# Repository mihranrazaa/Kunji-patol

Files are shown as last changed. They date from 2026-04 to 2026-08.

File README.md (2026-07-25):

# KUNJI-PATOL-75% KEYBOARD!

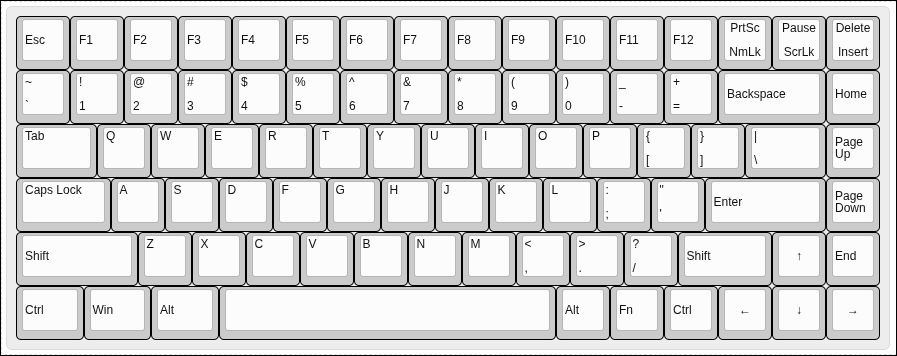
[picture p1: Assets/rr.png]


## Overview
a 75%% keyboard design, it is based on RP2040 plus with a type C port which came in-built with the MCU, there total of 87 MX switches with 5 Stabilizers. A complete keyboard :).


### Working Video

<video src="https://cdn.jsdelivr.net/gh/mihranrazaa/Kunji-patol@main/Assets/working.mp4" controls width="100%"></video>

I can't add the video on readme as it the file is big.. i have added it in the assets folder.. 
But here is the GDrive link [Link](https://drive.google.com/file/d/1fuCprYtJpbeOFGNmlc98sxJG4bjCoqw0/view?usp=sharing)

---

## Bit in depth info
The keyboard is designed to be sleek and plane it has RP2040 plus as the MCU and Cherry MX Brown Switches for the keys which are used for versatile purposes (that's what i saw at least). The main firmware is KMK based and the Firmware has already been released, you can find that in the Firmware and Production folder, I hate using different cables so having type c inbuilt in the RP2040 plus is a win-win. I tried to built a unique design but routing diodes was hell, at the end the pcb looks very good in black color, hope you like my project :).

---

## Files to build 

### PCB 

The files for the PCB and Schematics are available in the Kicad folder and gerber files are added in the Production folder..

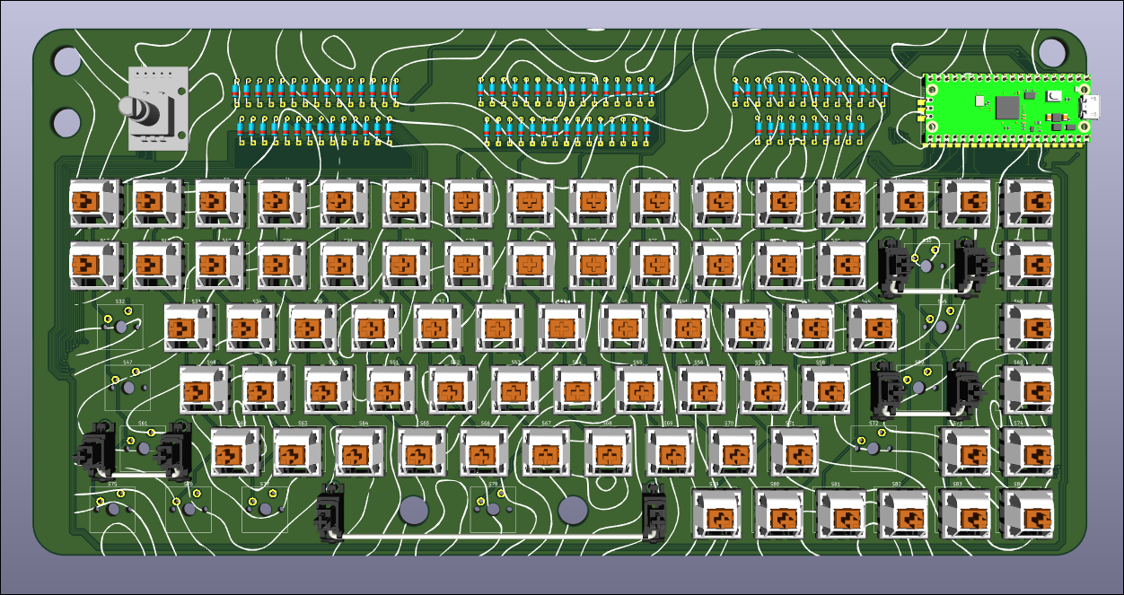
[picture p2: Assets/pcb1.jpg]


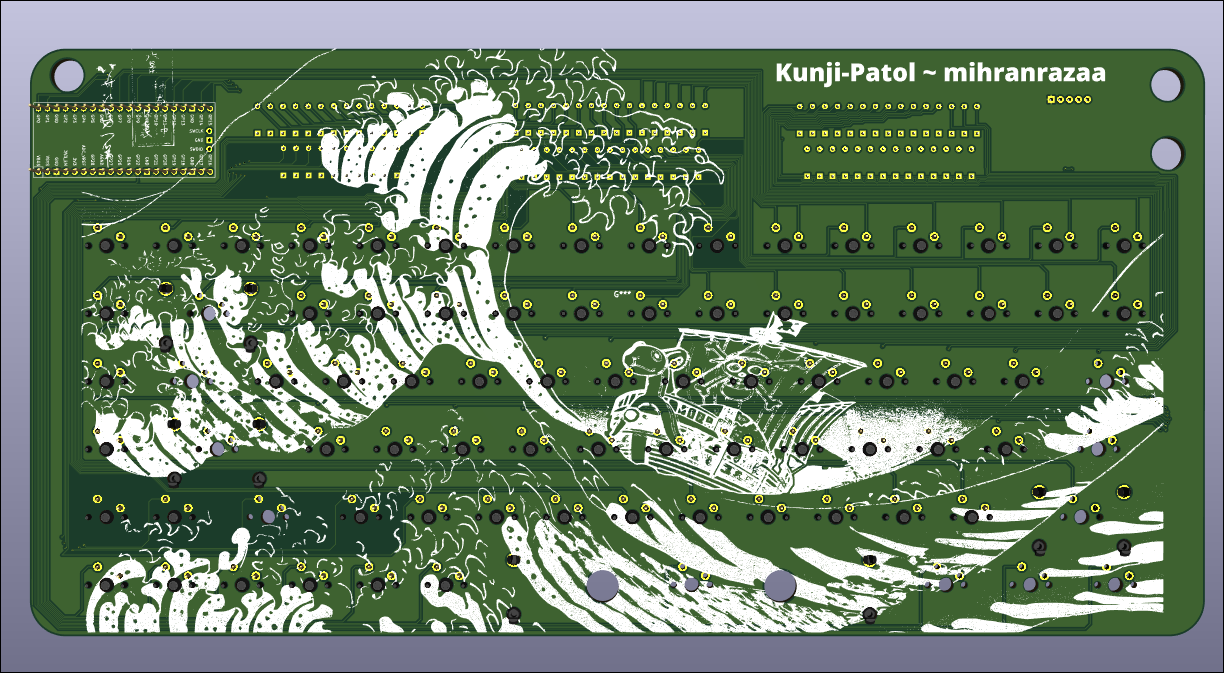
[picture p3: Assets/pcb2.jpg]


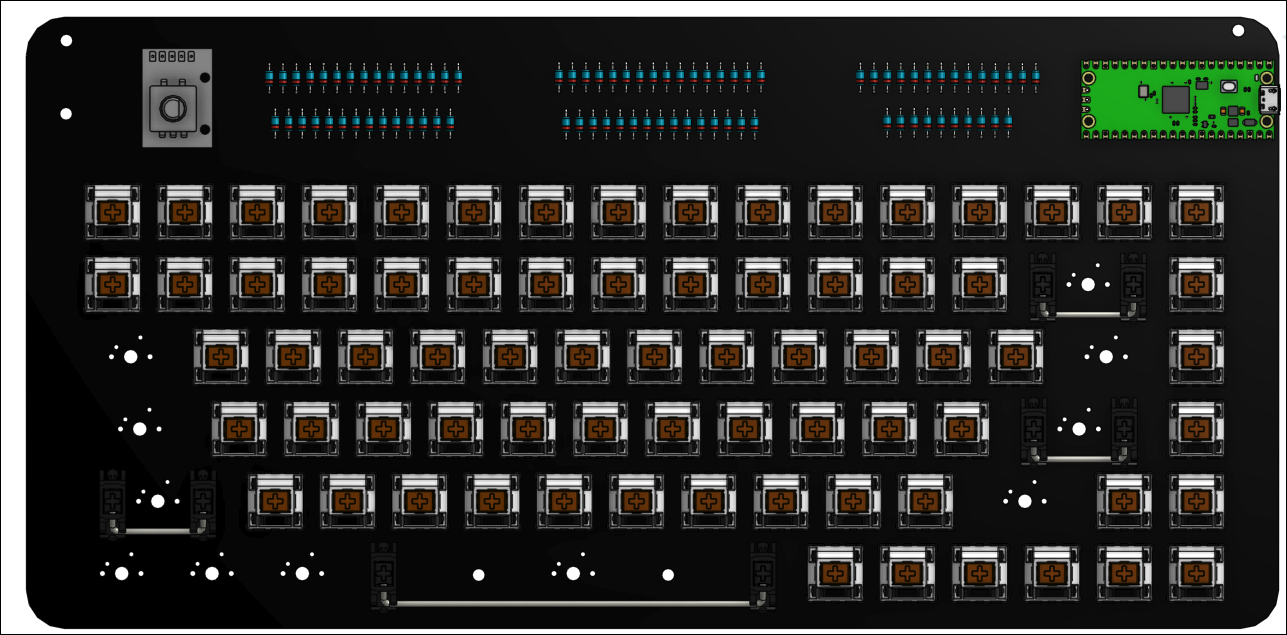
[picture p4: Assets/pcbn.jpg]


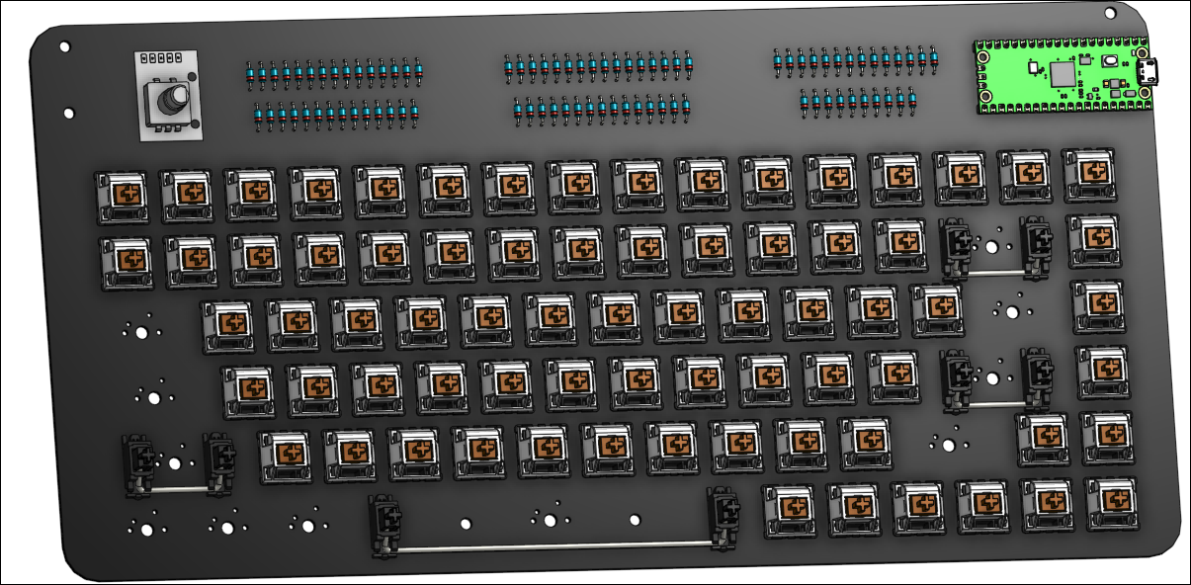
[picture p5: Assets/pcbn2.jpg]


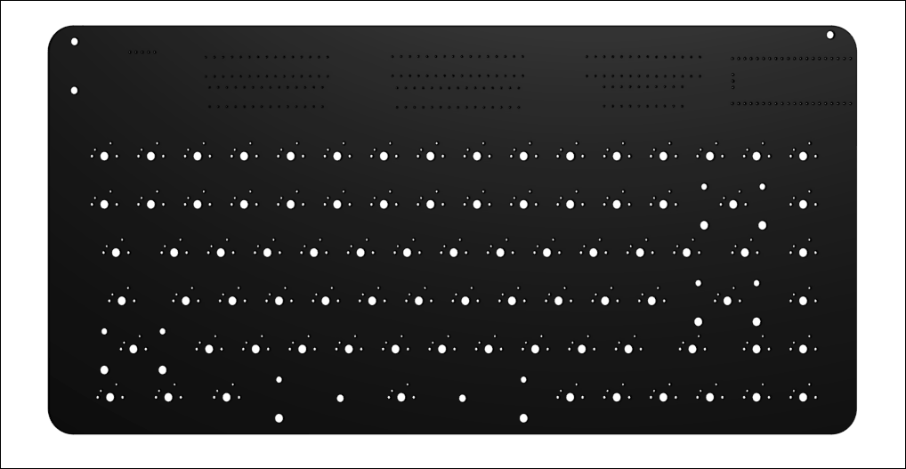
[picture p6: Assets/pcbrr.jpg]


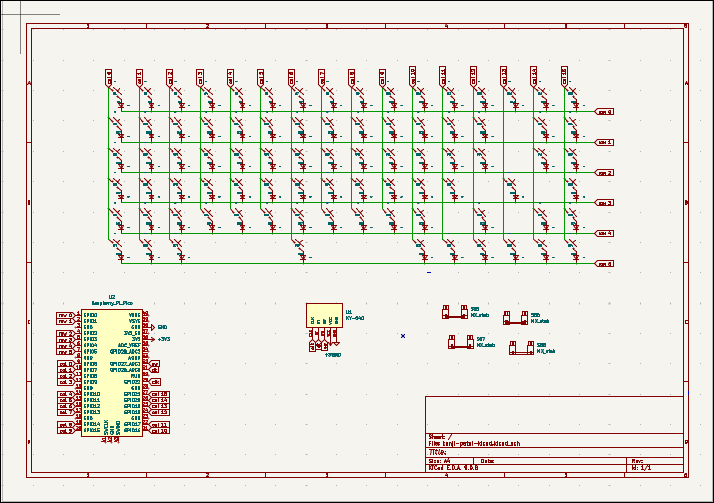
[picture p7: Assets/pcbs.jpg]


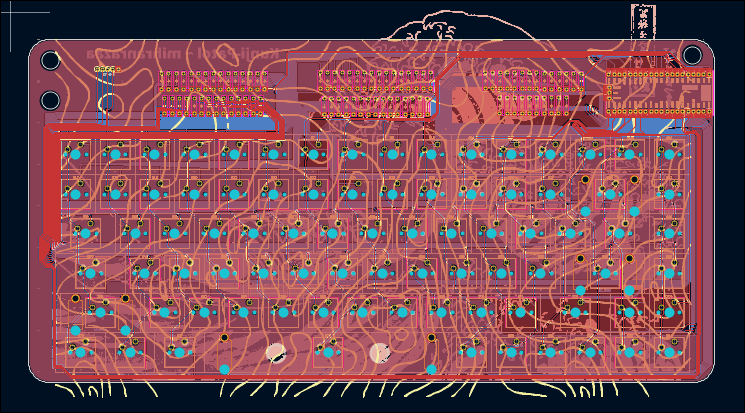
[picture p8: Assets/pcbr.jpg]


## Images

The files for case and plate cover are available in CAD folder and in production folder, you can also but acrylic sheet for the transparent plate.

Onshape Link - [Here](https://cad.onshape.com/documents/a8c5ad1b41baae53f41fa56c/w/8619affa68464bad5057e5ce/e/6ca96762f7cb8c02978ccc82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)

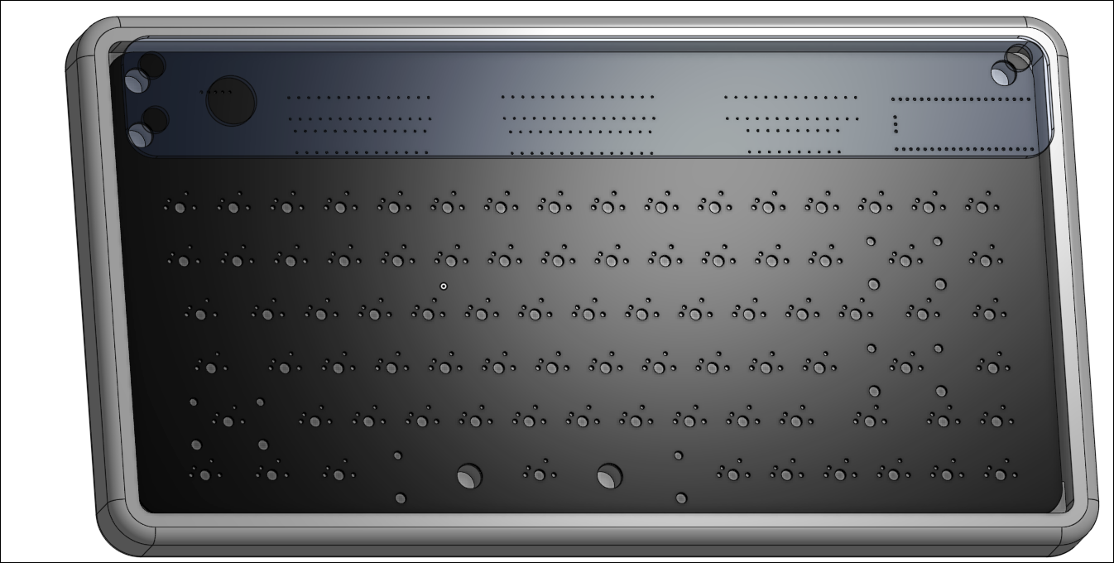
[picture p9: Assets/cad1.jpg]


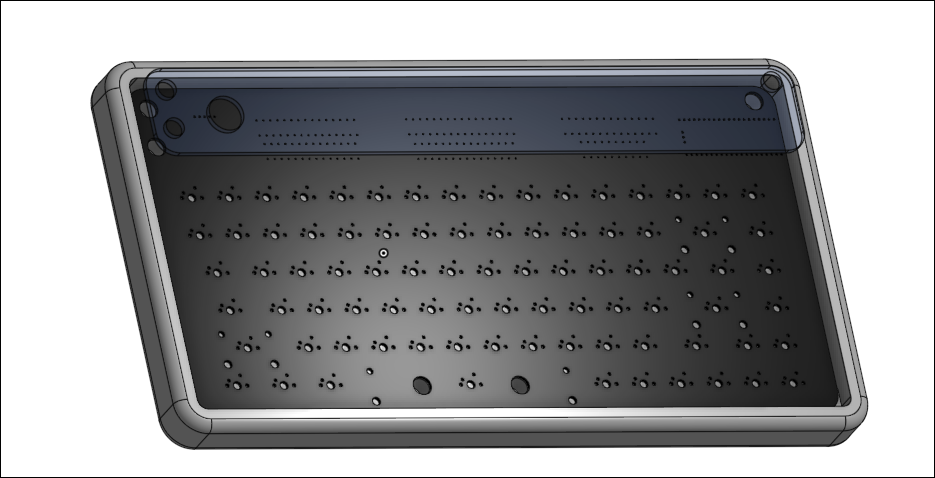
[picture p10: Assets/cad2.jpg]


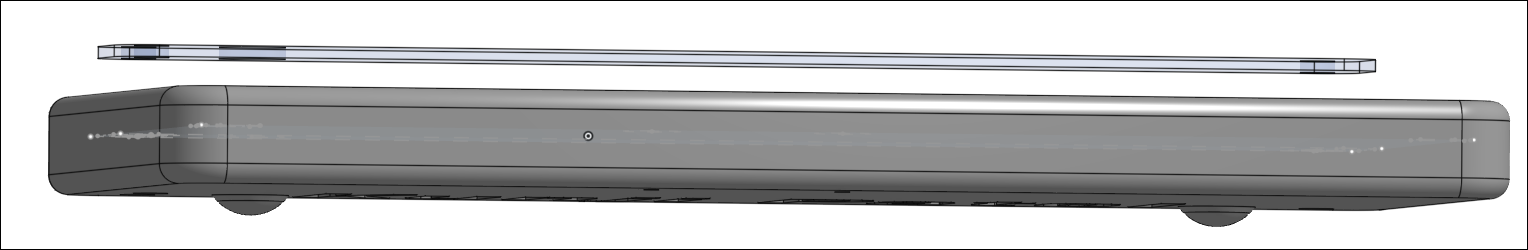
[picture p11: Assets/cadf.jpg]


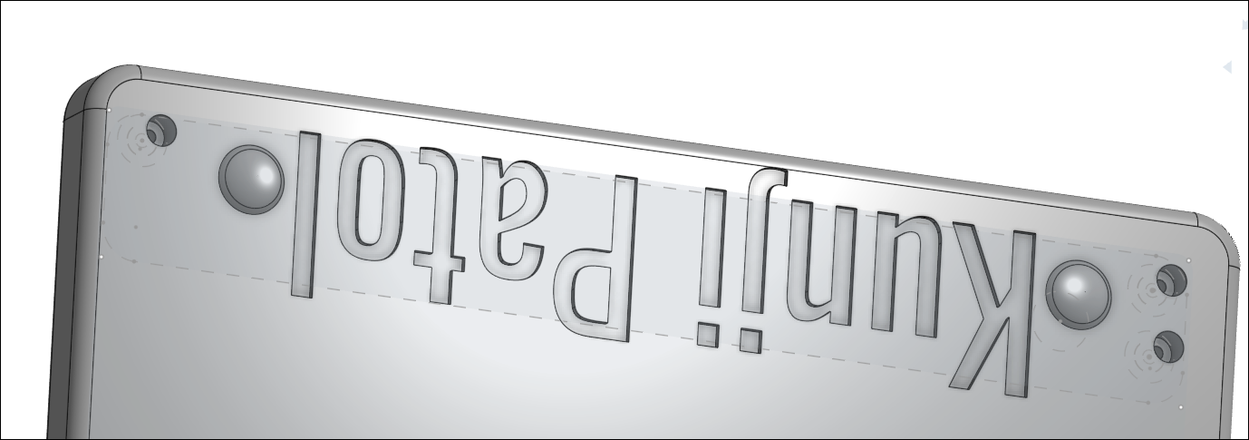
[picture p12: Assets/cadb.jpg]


NEW VERSION CAD

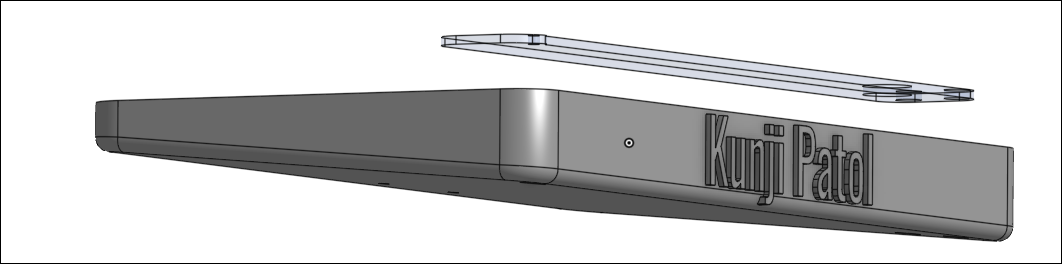
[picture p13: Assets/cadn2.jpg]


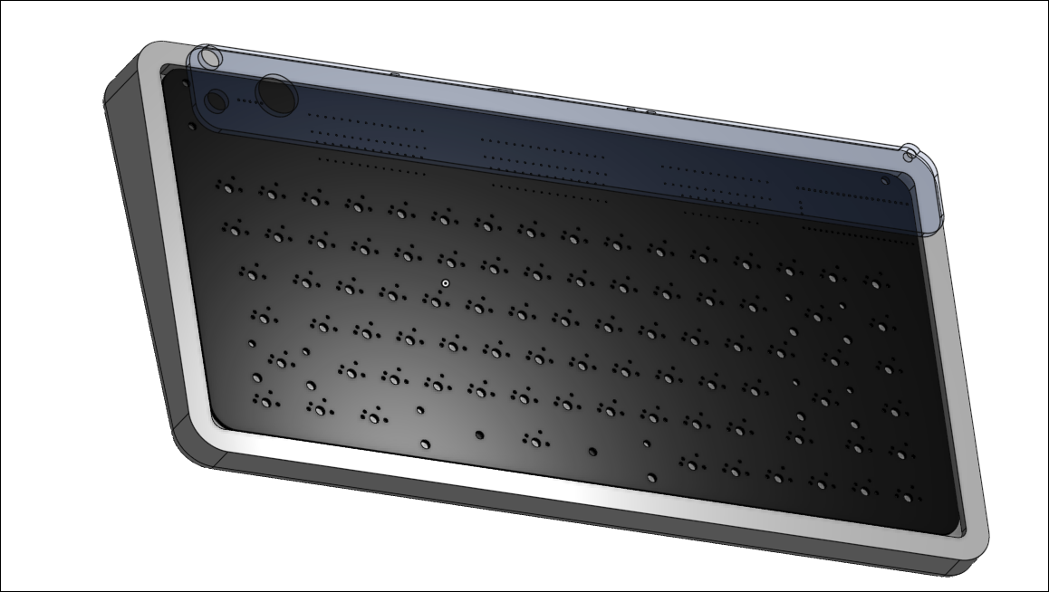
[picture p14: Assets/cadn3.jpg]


### Complete Assembly :)

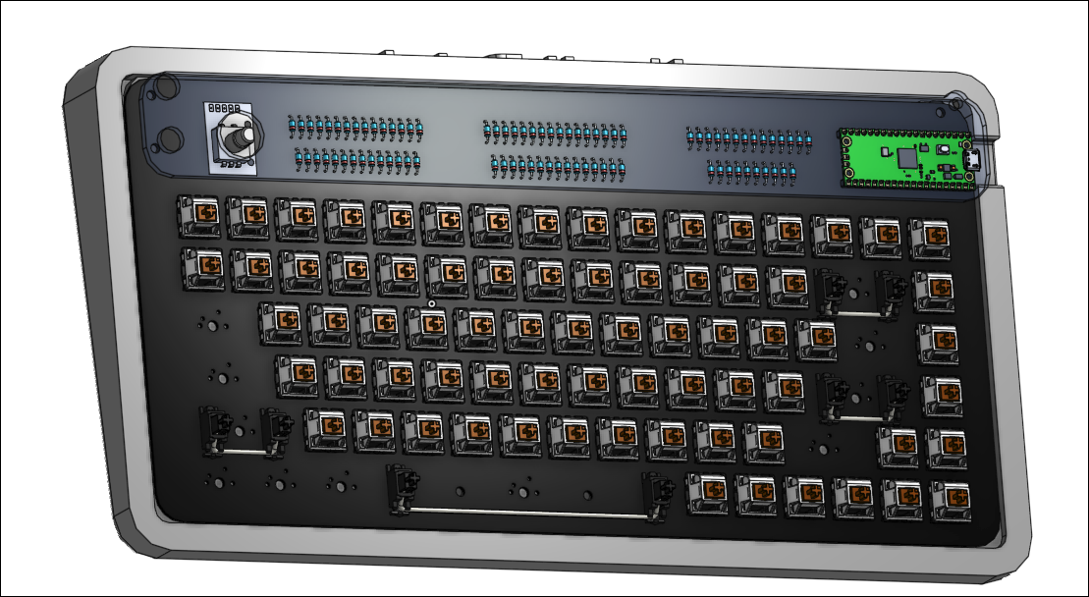
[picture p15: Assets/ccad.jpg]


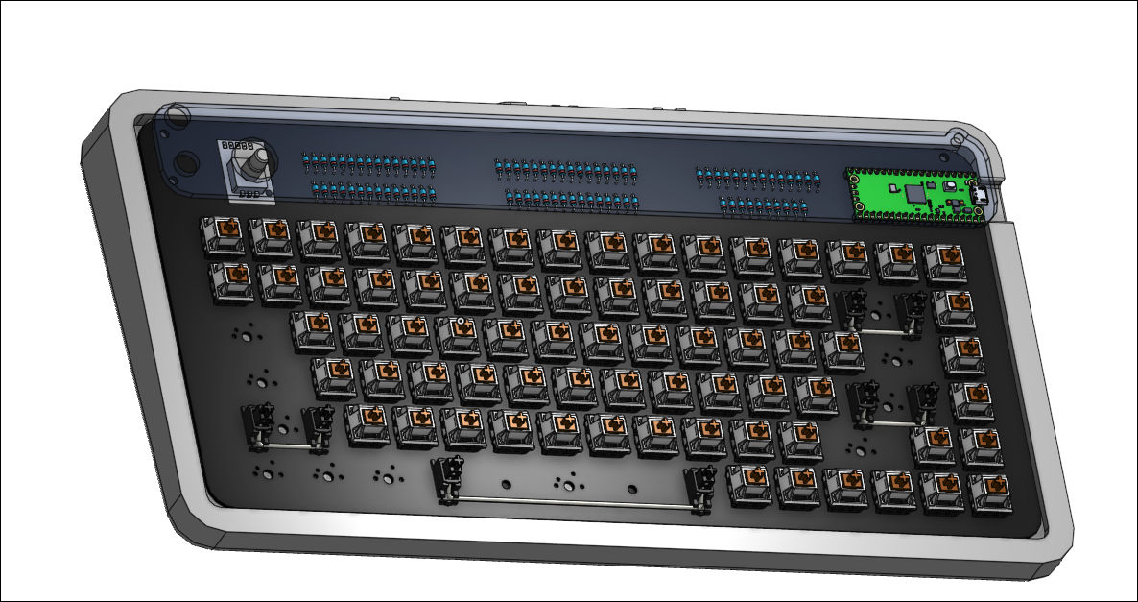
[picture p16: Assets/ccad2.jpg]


## Zine

Zine PDF is available in Production

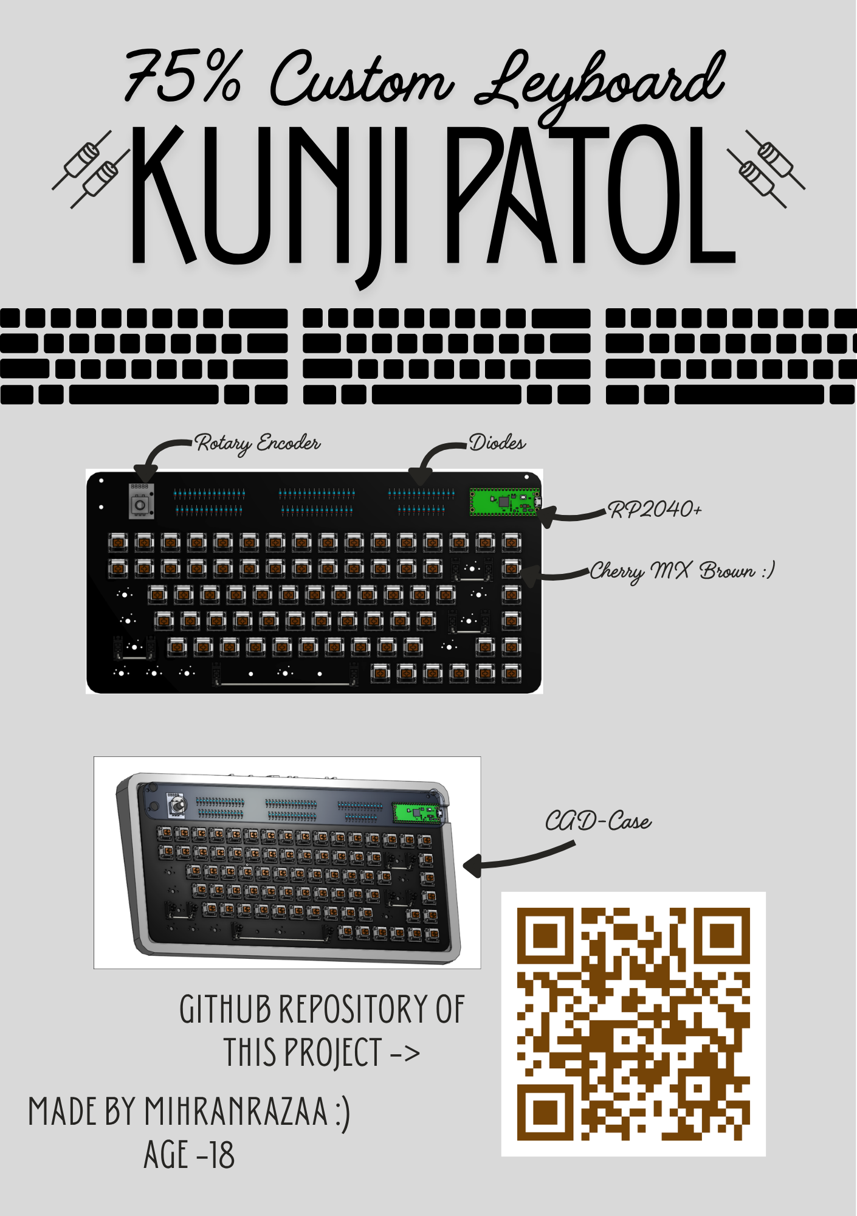
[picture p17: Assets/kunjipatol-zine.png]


---

## Motivation

### Why
I saw a similar design somewhere and i really liked it + i wanted a keyboard, so I built one for myself! 

## How

I is very easy just solder all the components and upload the KMK firmware on the mcu and it should work if everything is done correctly!. You can read the KMK [documentation](https://github.com/KMKfw/kmk_firmware/blob/main/docs/en/README.md) for detailed info on flashing, it is very easy to follow. 

---

## BOM

| Component | Quantity | Note | Price | Link |
| --- | --- | --- | --- | --- |
| Akko Yello creamy | 2 | Found a good website!! | 25USD | [Available](https://stackskb.com/store/akko-v5-creamy-yellow-pro-switch-pack-of-45/) |
| Grey Keycaps set | 1 | Good Asthetics are important I will keep the body grey :) | 16USD | [Available](https://stackskb.com/store/white-grey-and-yellow-double-shot-abs-cherry-profile-keycaps/) |
| Stabilizer set | 1 | PCB Mounted Stabs| 17USD | [Available](https://stackskb.com/store/durock-smokey-screw-in-stabilizers-v2/) |
| Case & PCB | 1 | This is the cheapest i could find | 63USD | https://robu.in/ |
| TOTAL | | | 70USD (needed)  | |

*I have some parts already + M3 screws and heatset inserts are not included as i already have them, one pack of each is more then enough.
I just need Pcb and Stabilizers :)

---

made with <3 by [mihranrazaa](https://mihranrazaa.info/)

BYEEE

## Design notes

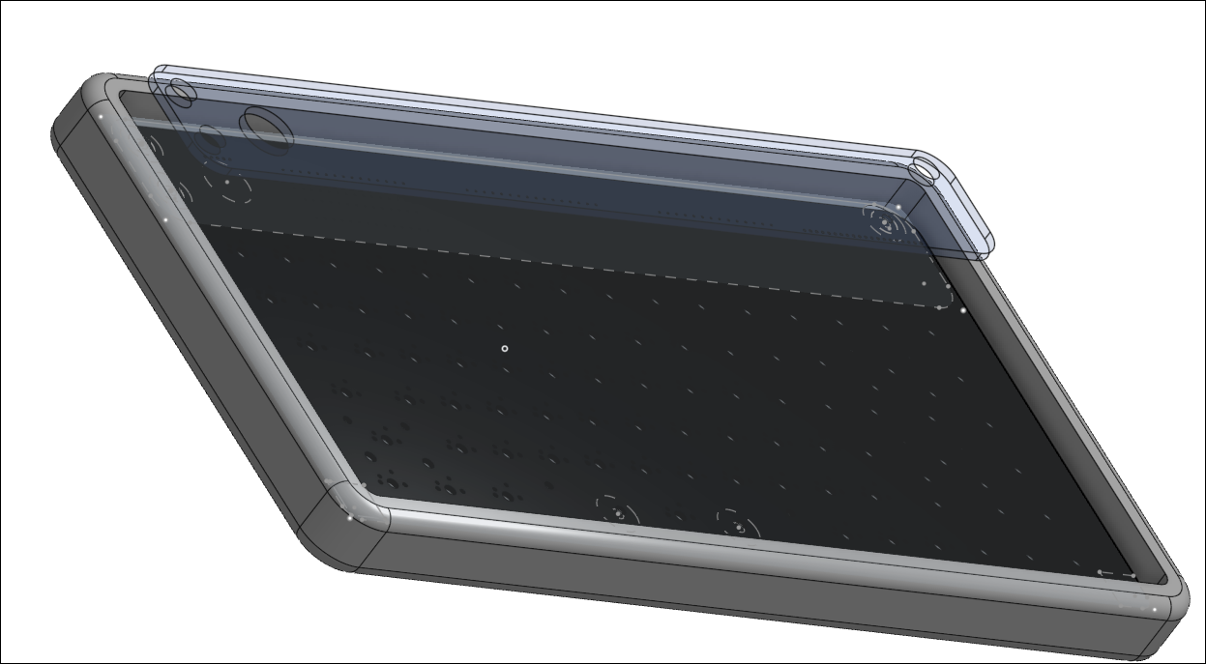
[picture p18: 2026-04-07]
Assets/cadn.jpg

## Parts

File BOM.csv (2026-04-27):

Name | Quantity | Price(USD) | Links | Notes(if any)
Akko Yello creamy | 2 | 25 | https://stackskb.com/store/akko-v5-creamy-yellow-pro-switch-pack-of-45/
Keycaps | 1 | 16 | https://stackskb.com/store/white-grey-and-yellow-double-shot-abs-cherry-profile-keycaps/
Stabilizer set | 1 | 17 | https://stackskb.com/store/durock-smokey-screw-in-stabilizers-v2/
Rotary Encoder | 1 | 1.5 | https://www.amazon.in/KitsGuru-Rotary-Decoder-Encoder-Module/dp/B01HHRJXS8
Case & PCB |  | 63 | https://robu.in/
Diodes | 87 | 4-5 | https://www.amazon.in/Circuit-Ranger-Switching-Electronic-Projects/dp/B0FJLP12GX

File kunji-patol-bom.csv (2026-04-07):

Name | Quantity | Price(USD) | Links | Notes(if any)
Cherry MX Switches(Brown) | 87 | 32 | https://www.keychron.com/products/cherry-switch-set?variant=39298816835673
Keycaps | 1 | 25 | https://www.keychron.com/products/cherry-profile-double-shot-pbt-full-set-keycaps-dolch-red-gray-white-mint-blue-black-yellow
Stabilizer set | 1 | 15 | https://amzn.in/d/5Nto8PQ
Rotary Encoder | 1 | 1.5 | https://www.amazon.in/KitsGuru-Rotary-Decoder-Encoder-Module/dp/B01HHRJXS8
Case & PCB |  | Printing Legion and Local PCB

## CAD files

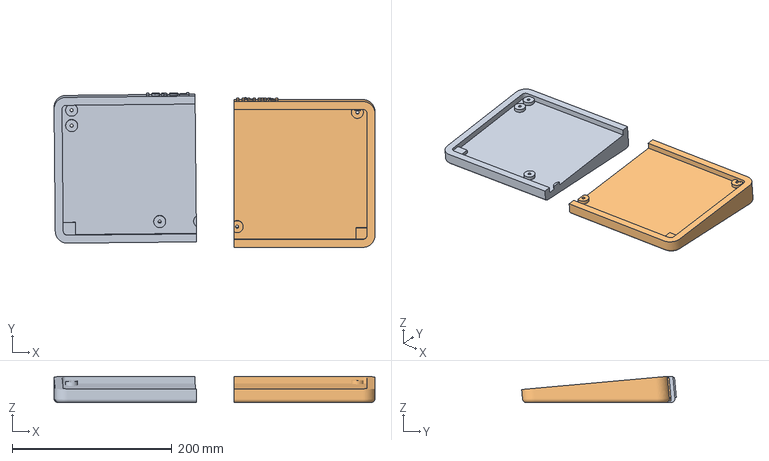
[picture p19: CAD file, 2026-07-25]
Production/Kunji-Patol-keyboard-base.3mf
401.3 x 193.5 x 32.9 mm
keyboard-base_A
keyboard-base_B

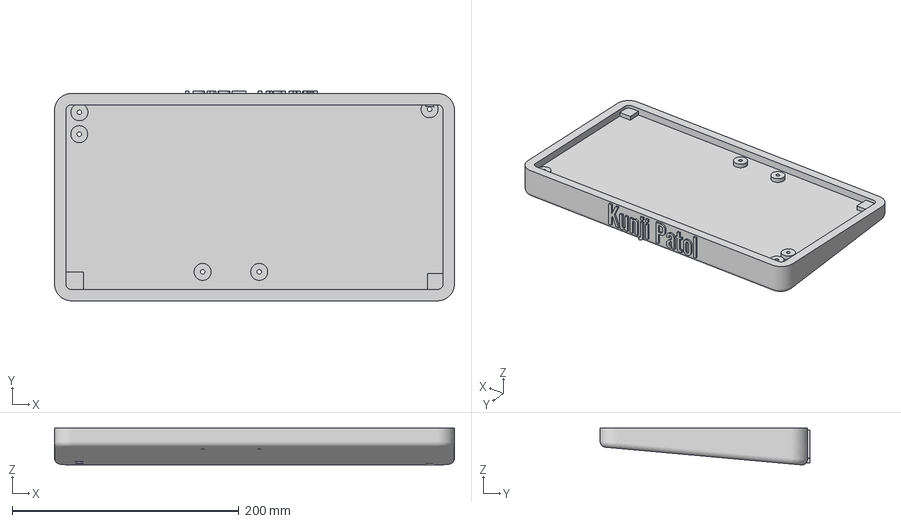
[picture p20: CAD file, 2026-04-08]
CAD/Kunji-Patol-keyboard-base.3mf
353.0 x 185.0 x 32.5 mm

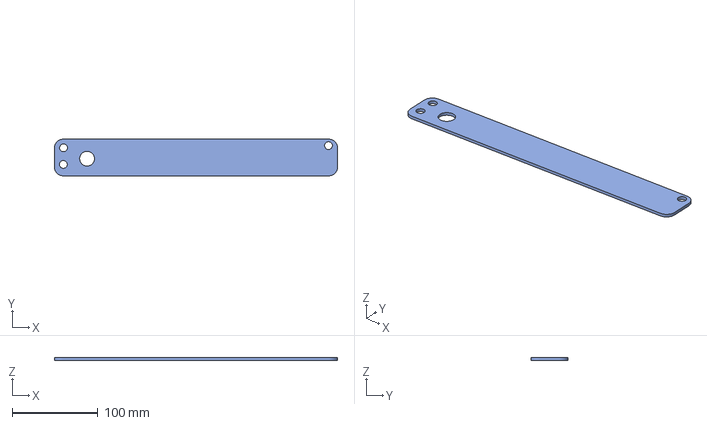
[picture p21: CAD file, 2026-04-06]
CAD/Kunji-Patol-transparent-cover.3mf
330.0 x 42.8 x 3.00 mm

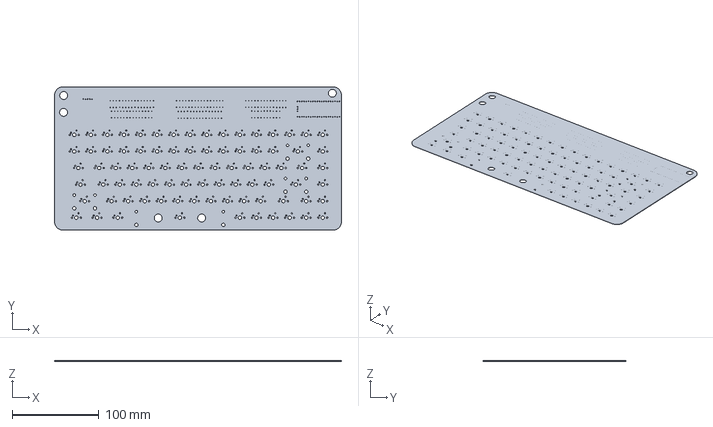
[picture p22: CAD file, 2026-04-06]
CAD/Kunji-Patol-kunji-patol-kicad_PCB.3mf
330.1 x 165.0 x 1.51 mm

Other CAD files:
CAD/Kunji-patol-Assembly.step
Production/Kunji-patol-Assembly.step

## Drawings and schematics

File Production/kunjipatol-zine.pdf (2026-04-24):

# 75% Custom Leyboard KUNJIPATOL

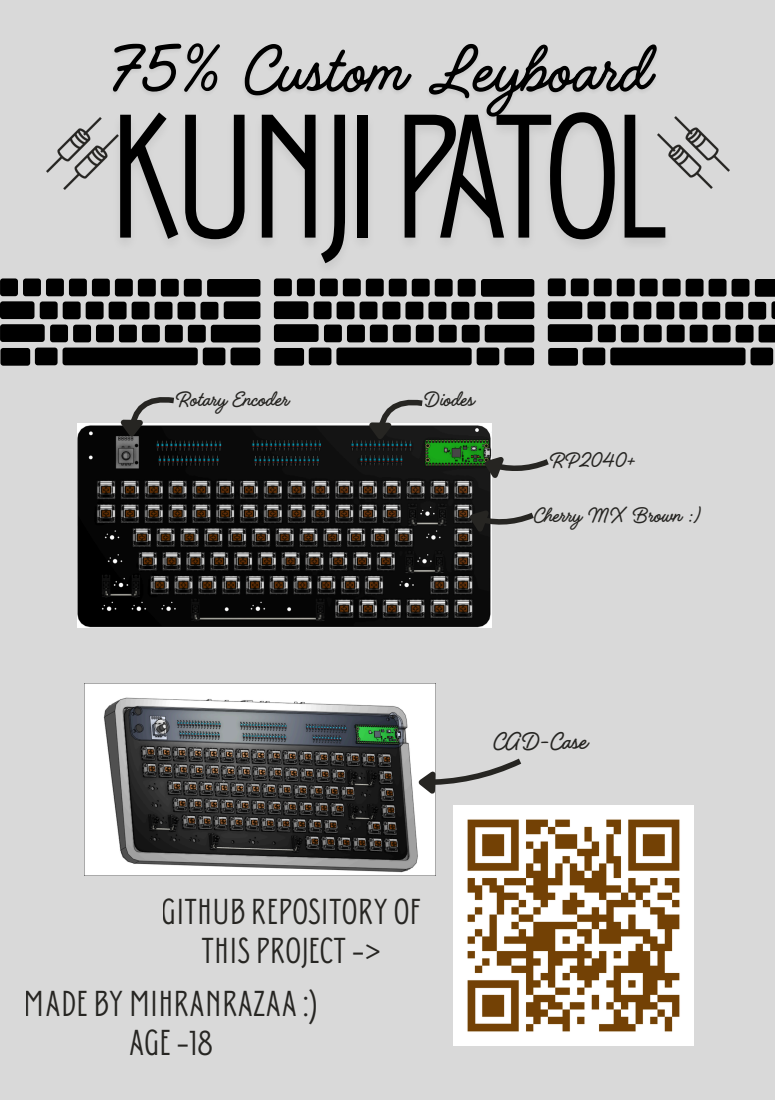
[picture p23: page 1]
Rotary Encoder; Diodes; CAD-Case

Cherry MX Brown :)

GITHUB REPOSITORY OF
THISPROJECT->

MADE BY MIHRANRAZAA :)
AGE-18

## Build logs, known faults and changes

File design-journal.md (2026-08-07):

# March 11: Completed the first session!

Planning :
I already roughly know what parts i want to use for my keybaord, I'll be using Cherry mx brown switches no backlight, and will decide on the keycaps latter, i used the hackpad for the basic walkthrough to get the needed idea on what to do ## What i did :
figured the no. of keys i will be using and the layout for it.
Used joe skotto lib and hackpad guide, for the symbols, footprints, etc. Also helped me with schematics..
Completed the basic schematic structure all left is to actually connect stuff with the MCU and also i will be adding volume control (potentiometer).
Here are the images of the process::

final layout---

image (7)
image (6)
image (5)

**Total time spent: 1hour 14minutes**

# March 13: Schematics Done! (2:04 AM)

Completed the schematics, thought of adding led indicator but then dropped the plan, I have one issue, i dunno how, but the i'm not able to see the route of pico with switches i'll ask later in channel, also 1 switch is left dunno how that happen i'll figure that in the next session. BYEEE here are the imagees of during work




**Total time spent: 1hour 18minutes**

# March 13: Started routing! (8:26 AM)

resolved that issue, it was just i interchanged the footprints of encoder and rpi pico, lol. Did some routing, was making the edges of pcb but i will do that after a short break here are some images while i was working








**Total time spent: 2hour 2minutes**

# March 13: MCU! (10:13 AM)

I f'ed up : /
I had to keep the MCU to the edge of MCU so i can connect the type c port properly ahhh. I need to redo the rows routing : / i'll do that later now :sob


**Total time spent: 35minutes**

# March 14: same Issue

Fixing the issue which i explained previuosly also changing the pcb edge/shape..
i'm making the corners more curved, plus i'll try to reduce the size of the pcb

the image id of previuos session as currently i don't have any ss of this session. BYE



**Total time spent: 31minutes**

# March 14: Finished PCB (8:18 AM)

Completed the PCB board!!!!, i still need to figure out where do i have to put holes, so they stay fixed in the case. + filled with gnd after lapse recording..

Here are the images of the sessions:





**Total time spent: 1hour 15minutes**

# March 15: CAD

Failed Sketch session :/ , it doesn't let me select the inner shape :sob i think it is becuase of spline which i used for curves next time i will try to ue only lines, and then use sketch fillet.



**Total time spent: 34minutes**

# March 15: CAD (3:00 AM)

Finaly i can sleep, atleast it is something.. Now i will see some keyboard designs and internal and copy whatever is good my keeb :lol


**Total time spent: 26minutes**

# March 15: CAD (10:10 PM)

Ah, My cad was lagging becuase of two many moving components and my slow (during recording )wifi i think, so i stopped and will continue when do my work in my room
Nothing special, working on the case, still need more idea on how actually my case should look....



**Total time spent: 31minutes**

# March 16: CAD

Yeah, struggling like crazy for a good case or look, i was thinking the pcb was lookinig good but with cad i can't think a very good way + who i was harrased by a screw :sob anyways that is all. I'm considering changing my pcb shape and making it like one of those which have a transparent sheet on top...


**Total time spent: 1hour 17minutes**

# March 16: New PCB

ALright the the new design of pcb has started to take shape, i had to clear doubt that doing this is not considered inflating time, thankfully it doesn't...





**Total time spent: 44minutes**

# March 16: PCB (11:11 AM)

Anothernot very good sessionS, in the 11th session i'm mostly wandering around and playing with how i want to place the pcb as pcb shape will be very important for my cad (atleast for how i'm thinking it comes out) but honestly i thought this might get considered as time inflation so i didn't journeld it as a single lapse, like how i do it, but i'll add it anyways upto the reviewer ::lol.

Second session : I Starterd focusing on routing it first as i think that will give me a much clear picture on how large the pcb needs to be, so i did and then i came to another problem diode placement it is a big web of unrouted lines rn , so i have to simplify it by organizing all the diodes properly so they can be routed properly
That is it for today.. BYEE

THE WEB :::


**Total time spent: 1hour 17minutes**

# March 17: Routing



Yay: Lots of work done, started routing, organized the diodes properly and did one row, not this work will just take some more time

**Total time spent: 1hour 13minutes**

# March 18: Routing



Done another row, now i''m thinking hwo will i route the coloumns? huh guess will figure that out later...

**Total time spent: 32minutes**

# March 26: Fixing



i was working on fixing the routes and got some things to do so paused but i might have pressed finished i guess

**Total time spent: 7minutes**

# March 25: Routing

Alright i might have to fix the current routing which i just did :sob, the diodes idea looks goood but routing is such a hassle, i forgot i route columns too, so first i have to make a way for columsn so they can be routed properly then other rows .....


**Total time spent: 13minutes**

# March 26: PCB

Routed some columns and part of rows, and i have a feeling i might get more issues in routing the diodes :sob, i swear though if this gets completed it willl look really really goood, the whole pcb....

see the 3d view



**Total time spent: 45minutes**

# April 6: Routing

AH did some more routing, only one row remains then i will do the mcu and encoder, i know this is not the best routing work, but if i redo from scratch again it would take a long time and i'll prolly get banned for time-inflation :lol, anyways i'm close to done!!


**Total time spent: 47minutes**

# April 6: Routing

Did more routing, all switches done, found a way to route encoder too (i thought that wouldn't be possible:sob), after routing i will fill gnd so no need to route gnd. that's all...


**Total time spent: 37minutes**

# April 6: Completed

Completed the full pcb, and also did most of my work for the case!! the case is easy as most of it is already very open so i'm good.



**Total time spent: 1hour 6minutes**

# April 7: CAD



Done with the project now. also i forgot to turn on the recording :sobin, but it's ok now i have to make zine which i don't know how to but i'll do somwthing, ok that's all byee

**Total time spent: 46minutes**

# April 9: CAD



Improved the cad case, added a tilt though i know it better to have a flat case for your joints, but it was not looking good :sob, added the name in front rather then in down..

**Total time spent: 49minutes**

# April 25: Fixes

FIxed all the issue at first i thought only zine requires actual changes but reviewer also pointed oiut the that cap of cable might not go through which i didn't thought of so done thank you for that :) that' s all BYEEE also fixed zine, added complete step, and images..


**Total time spent: 30minutes**

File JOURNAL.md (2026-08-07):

---
title: "Kunji-Patol"
author: "mihranrazaa"
description: "A 75% mechanical keyboard, because i need one!"
created_at: "2026-03-11"
---

# May 29 : IRL Build 
So after a long long break i'm back!!!!
I ordered the parts which i didn't have which is only pcb heheh, i had all the stuff already i had to wait for my pcb for a long time as a from where i ordered it from though is the cheapest option but it takes 15-20 days to arrive, so it took its sweet time, after it arrived i started with soldering the diodes, then swtiches. i didn't had any problems soldering diodes but man the switches uh
I could only solder two or max 3 switches at time, as they were so loose on pcb + i didn't had any helping hand tools to make the process easier i tried using tape 3 times all the time it failed miserably. anyways i completed soldering switches after that i solder my MCU RP2040 plus, that was very easy and i enjoyed that, then my rotary encoder had already soldered pins so i had top remove them as  they were bent and were upside down but while removing the pad came out of clk pin so i have to reorder it till then i made a firmware for the keyboard i started with normal QMK based firmware but later added VIA functionality which is peak literally as that does not require flashing firmware again and again. SO only few things remians, the rotary encoder, and the base case which i will redesign  after doing some research on how much incline is better for keyboard, though i'm writing this with my keybaord only :) it works amazing!! it feels very different from my laptop membrane keyboard, plus the SOUND !!, anyways that's all i'll update when i start with the new case design and when i order my new rotary encoder. 
That's all for now.. 

Here are the images!!

IMG-20260526-WA0000




**Total time spent: 4hours**

# July 25 : CRINEE

Wased so much time just to add video in readme, i first tried to do it normally but the file was big so i had to upload it through LFS but that too didn't worked how i wanted it to be, AI suggested upload it in issue it will create a link add that link in readme that shit too didn't worked file was faliing to upload again and again.. i even compressed it but that too didn't worked ... but not i have just gave a link to googgle drive and added video in the repo assets.. now i will resubmit


**Total time spent: 40minutes**

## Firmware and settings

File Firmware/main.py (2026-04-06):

import board
from kmk.kmk_keyboard import KMKKeyboard
from kmk.keys import KC
from kmk.matrix import DiodeOrientation
from kmk.modules.layers import Layers
from kmk.extensions.media_keys import MediaKeys
from kmk.modules.modtap import ModTap

keyboard = KMKKeyboard()

keyboard.modules.append(Layers())
keyboard.modules.append(ModTap())
keyboard.extensions.append(MediaKeys())


keyboard.row_pins = (
    board.GP0,   # Row 0
    board.GP1,   # Row 1  
    board.GP2,   # Row 2
    board.GP3,   # Row 3
    board.GP4,   # Row 4
    board.GP5,   # Row 5
)

keyboard.col_pins = (
    board.GP6,   # Col 0
    board.GP7,   # Col 1
    board.GP8,   # Col 2
    board.GP9,   # Col 3
    board.GP10,  # Col 4
    board.GP11,  # Col 5
    board.GP12,  # Col 6
    board.GP13,  # Col 7
    board.GP14,  # Col 8
    board.GP15,  # Col 9
    board.GP16,  # Col 10
    board.GP17,  # Col 11
    board.GP18,  # Col 12
    board.GP19,  # Col 13
    board.GP20,  # Col 14
    board.GP21,  # Col 15
)

keyboard.diode_orientation = DiodeOrientation.COL2ROW



# layers
keyboard.keymap = [
    # Layer 0
    [
        KC.ESC,    KC.F1,   KC.F2,   KC.F3,   KC.F4,   KC.F5,   KC.F6,   KC.F7,   KC.F8,   KC.F9,   KC.F10,  KC.F11,  KC.F12,  KC.PSCR, KC.SLCK, KC.PAUS,
        KC.GRV,    KC.N1,   KC.N2,   KC.N3,   KC.N4,   KC.N5,   KC.N6,   KC.N7,   KC.N8,   KC.N9,   KC.N0,   KC.MINS, KC.EQL,  KC.BSPC,          KC.INS,  KC.HOME, KC.PGUP,
        KC.TAB,    KC.Q,    KC.W,    KC.E,    KC.R,    KC.T,    KC.Y,    KC.U,    KC.I,    KC.O,    KC.P,    KC.LBRC, KC.RBRC, KC.BSLS,          KC.DEL,  KC.END,  KC.PGDN,
        KC.CAPS,   KC.A,    KC.S,    KC.D,    KC.F,    KC.G,    KC.H,    KC.J,    KC.K,    KC.L,    KC.SCLN, KC.QUOT,          KC.ENT,
        KC.LSFT,   KC.Z,    KC.X,    KC.C,    KC.V,    KC.B,    KC.N,    KC.M,    KC.COMM, KC.DOT,  KC.SLSH,          KC.RSFT,                            KC.UP,
        KC.LCTL,   KC.LGUI, KC.LALT,                   KC.SPC,                            KC.RALT, KC.RGUI, KC.MENU, KC.RCTL,          KC.LEFT, KC.DOWN, KC.RGHT,
    ],
    
    # Layer 1
    [
        KC.TRNS,   KC.TRNS, KC.TRNS, KC.TRNS, KC.TRNS, KC.TRNS, KC.TRNS, KC.TRNS, KC.TRNS, KC.TRNS, KC.TRNS, KC.TRNS, KC.TRNS, KC.TRNS, KC.TRNS, KC.TRNS,
        KC.TRNS,   KC.TRNS, KC.TRNS, KC.TRNS, KC.TRNS, KC.TRNS, KC.TRNS, KC.TRNS, KC.TRNS, KC.TRNS, KC.TRNS, KC.TRNS, KC.TRNS, KC.TRNS,          KC.TRNS, KC.TRNS, KC.TRNS,
        KC.TRNS,   KC.TRNS, KC.TRNS, KC.TRNS, KC.TRNS, KC.TRNS, KC.TRNS, KC.TRNS, KC.TRNS, KC.TRNS, KC.TRNS, KC.TRNS, KC.TRNS, KC.TRNS,          KC.TRNS, KC.TRNS, KC.TRNS,
        KC.TRNS,   KC.TRNS, KC.TRNS, KC.TRNS, KC.TRNS, KC.TRNS, KC.TRNS, KC.TRNS, KC.TRNS, KC.TRNS, KC.TRNS, KC.TRNS,          KC.TRNS,
        KC.TRNS,   KC.TRNS, KC.TRNS, KC.TRNS, KC.TRNS, KC.TRNS, KC.TRNS, KC.TRNS, KC.TRNS, KC.TRNS, KC.TRNS,          KC.TRNS,                            KC.VOLU,
        KC.TRNS,   KC.TRNS, KC.TRNS,                   KC.TRNS,                            KC.TRNS, KC.TRNS, KC.TRNS, KC.TRNS,          KC.MPRV, KC.VOLD, KC.MNXT,
    ],
]

keyboard.debounce_time = 10

keyboard.tap_time = 200

if __name__ == '__main__':
    keyboard.go()

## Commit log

2026-04-07 add new bom links
    [kicad-bom.csv, kunji-patol-bom.csv]
2026-04-07 fix filename
    [Kunji-Patol-keyboard-base.3mf, Kunji-Patol-kunji-patol-kicad_PCB.3mf, Kunji-Patol-transparent-cover.3mf]
2026-04-07 Update Case & PCB entry with retailer link
    Added a link for the Case & PCB section in the README.
2026-04-07 update bom
    [bom.csv, kicad-bom.csv]
2026-04-08 update case
    [Kunji-Patol-keyboard-base.3mf]
2026-04-25 Update JOURNAL.md with recent PCB progress
    Added detailed journal entries for PCB design and routing sessions, including time spent and images of progress.
2026-04-26 Revise pricing for components in README
    Updated pricing for Case & PCB and adjusted total cost.
2026-04-27 optimized BOM
    [BOM.csv]
2026-07-25 Add working video
    [Kunji-Patol-keyboard-base.3mf]
2026-07-25 Track large video with Git LFS
2026-08-07 Update JOURNAL.md with project progress
    Documented the progress and challenges faced during the mechanical keyboard project, including PCB design, routing, CAD, and IRL build experiences.
